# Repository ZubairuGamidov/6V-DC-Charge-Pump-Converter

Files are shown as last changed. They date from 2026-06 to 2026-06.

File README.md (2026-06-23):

# Low-Cost 6V DC-DC Charge Pump Converter

## 1. Introduction
The objective of this project is to design a low-cost charge pump circuit with a single input power source of 6V DC, satisfying all requirements like output load voltage, efficiency, voltage regulation, and cost-effectiveness. 

To meet these goals, the circuit utilizes an NE555 timer configured in astable mode to generate a switching signal. This signal is buffered by a BJT push-pull driver (using BC238 and BC308) to provide sufficient current to a multi-stage diode-capacitor voltage multiplier network. LTspice was used to build and test the circuit.

---

## 2. Design Specs & Laboratory Bench Results

The physical prototype was fabricated and tested in the laboratory using an oscilloscope, power supply, and multi-meter to verify compliance with design benchmarks:

* **Output Voltage (No Load):** Measured at **17.9V**, successfully staying under the maximum 20V constraint.
* **Output Voltage (Under $560\Omega$ Load):** Delivers a stable **16.2V**, comfortably exceeding the required 15.0V threshold.
* **Peak-to-Peak Output Ripple ($V_r$):** Measured at a very low **36.0mV** under full load, satisfying the noise restrictions.
* **System Power Efficiency ($\eta$):** Achieved **75.1%** overall efficiency during hardware testing.
* **Total Component Cost:** Calculated at **17.86 TL**, keeping the prototype well under the 20 TL budget cap.

---

## 3. Circuit Architecture
* **Astable Oscillator:** Configured via resistors $R_A = 1.2\text{k}\Omega$, $R_B = 12\text{k}\Omega$, and a $2.2\text{nF}$ ceramic capacitor to establish the system's operational switching frequency.
* **Buffer/Driver Stage:** A complementary BJT pair containing the **BC238 (NPN)** and **BC308 (PNP)** acting as a low-impedance high-current buffer to rapidly charge and discharge the multiplier network.
* **Multiplier Network:** A 2-stage voltage multiplication configuration utilizing four low forward-drop **1N5819 Schottky diodes** and $100\mu\text{F}$ electrolytic storage capacitors.

---

## 4. File Guide
* `Simulation/`: Contains the native LTspice transient simulation circuit file (`.asc`) and its corresponding analysis report.
* `Hardware/`: Contains the DipTrace schematic design (`.dch`) and hardware PCB layout (`.dip`) source files.
* `Production/`: Pre-packaged, standard-compliant Gerber and NC Drill manufacturing zip archive for automated fabrication.
* `Documentation/`: Full lab implementation report containing bench test photos, oscilloscope waveforms, and detailed efficiency metrics.

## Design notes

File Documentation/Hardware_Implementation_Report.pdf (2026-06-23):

### Low Cost DC-DC Converter

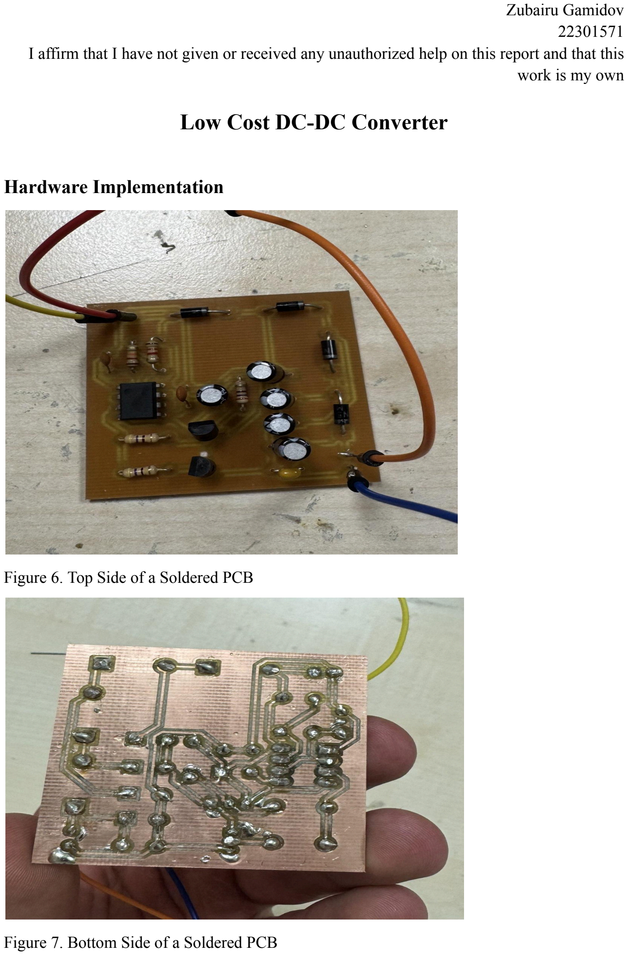
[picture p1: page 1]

Zubairu Gamidov
22301571
I affirm that I have not given or received any unauthorized help on this report and that this work is my own

Hardware Implementation

Figure 6. Top Side of a Soldered PCB

Figure 7. Bottom Side of a Soldered PCB

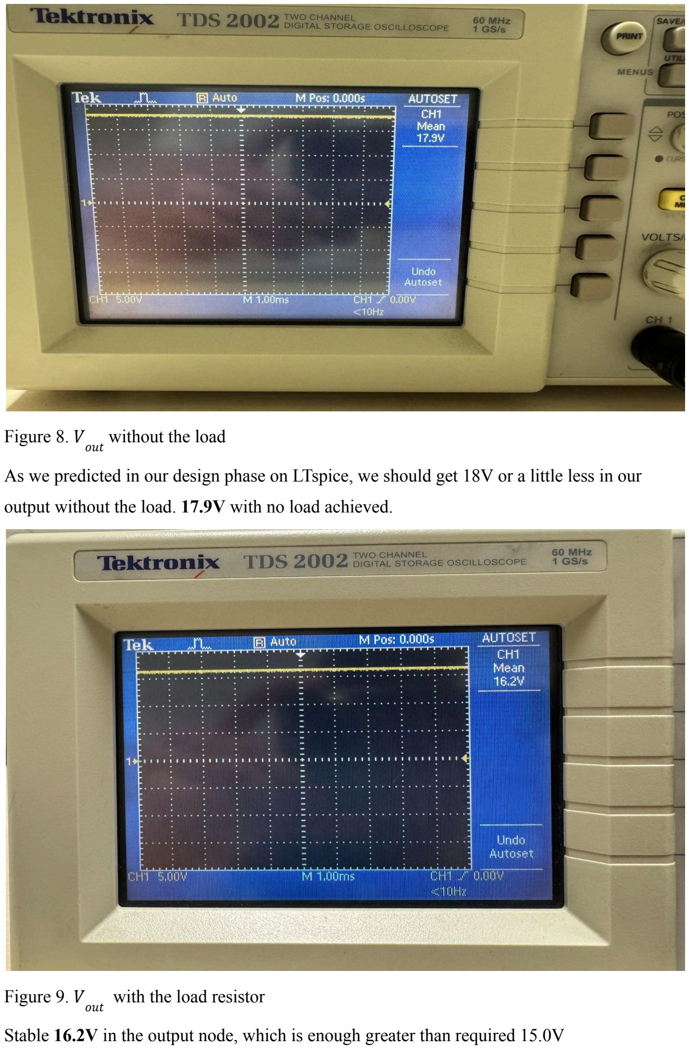
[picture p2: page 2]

Figure 8. V without the load
out
As we predicted in our design phase on LTspice, we should get 18V or a little less in our output without the load. 17.9V with no load achieved.

Figure 9. V with the load resistor
out
Stable 16.2V in the output node, which is enough greater than required 15.0V

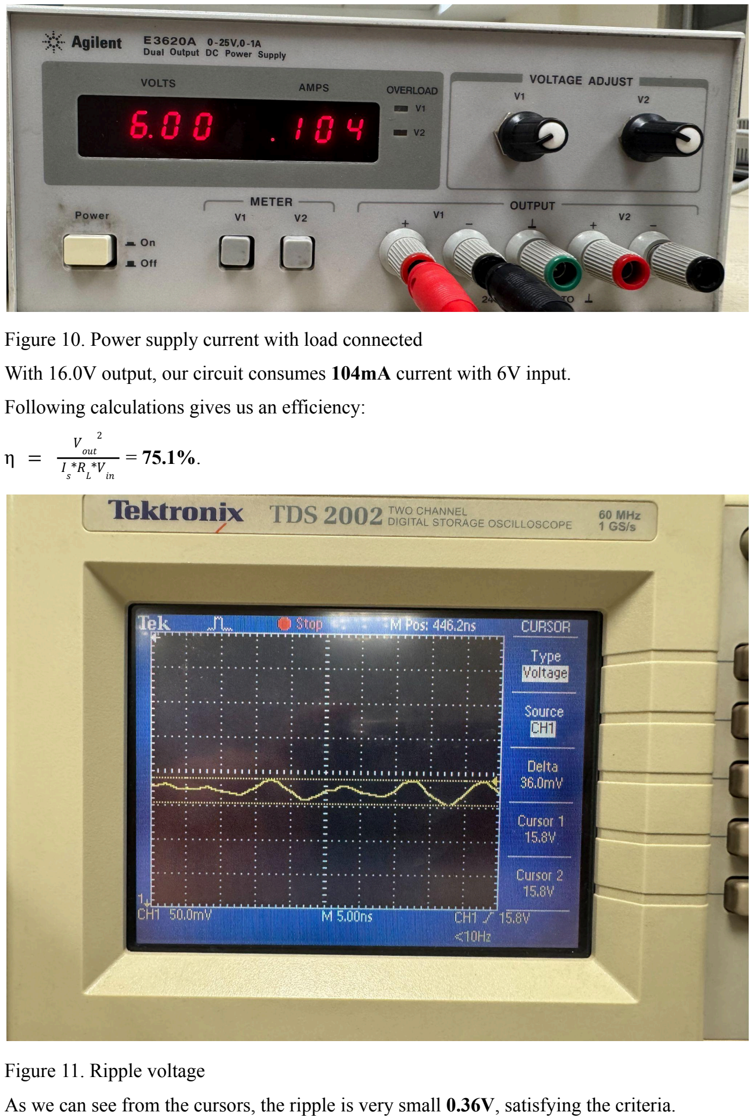
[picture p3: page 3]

Figure 10. Power supply current with load connected
With 16.0V output, our circuit consumes 104mA current with 6V input. Following calculations gives us an efficiency:
η = | = 75.1%.

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
Figure 11. Ripple voltage
As we can see from the cursors, the ripple is very small 0.36V, satisfying the criteria.

Components Cost

Component | Type | Quantity | Unit Price (TL) | Total (TL)
NE555 | Timer IC | 1 | 6.49 | 6.49
BC238 | NPN BJT | 1 | 1 | 1
BC308 | PNP BJT | 1 | 1.07 | 1.07
1N5819 | Schottky Diode | 4 | 1.06 | 4.24
100µF 25V | Electrolytic Capacitor | 5 | 0.7 | 3.5
2.2nF | Ceramic Capacitor | 2 | 0.29 | 0.58
0.47µF 63V | Ceramic Capacitor | 1 | 0.38 | 0.38
1/4W Resistors | Standard Resistors | 5 | 0.12 | 0.6
Grand Total | | | | 17.86 TL
Table 1. Cost Table

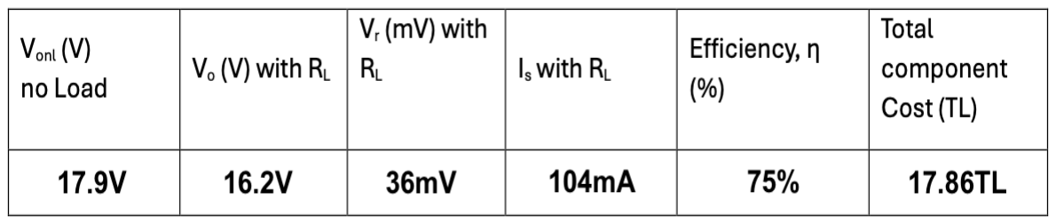
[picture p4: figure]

Figure 12. Final result table

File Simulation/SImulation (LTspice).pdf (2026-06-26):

Zubairu Gamidov
22301571

### Bilkent University

### EEE 313

### Charge Pump - Design Phase

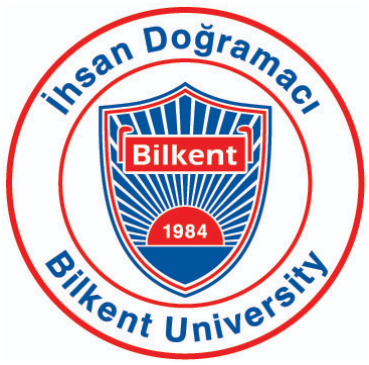
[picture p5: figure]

I affirm that I have not given or received any unauthorized help on this report and that this work is my own.

### 1. Introduction

The objective of this project is to design a low cost charge pump circuit with a single input power source of 6V DC, satisfying all requirements like output load voltage, efficiency, voltage regulation, and cost - effectiveness.

To meet these goals, the circuit utilizes an NE555 timer configured in astable mode to generate a switching signal. This signal is buffered by a BJT push-pull driver (using BC238 and BC308) to provide sufficient current to a multi-stage diode - capacitor voltage multiplier network. LTspice was used to build and test the circuit.

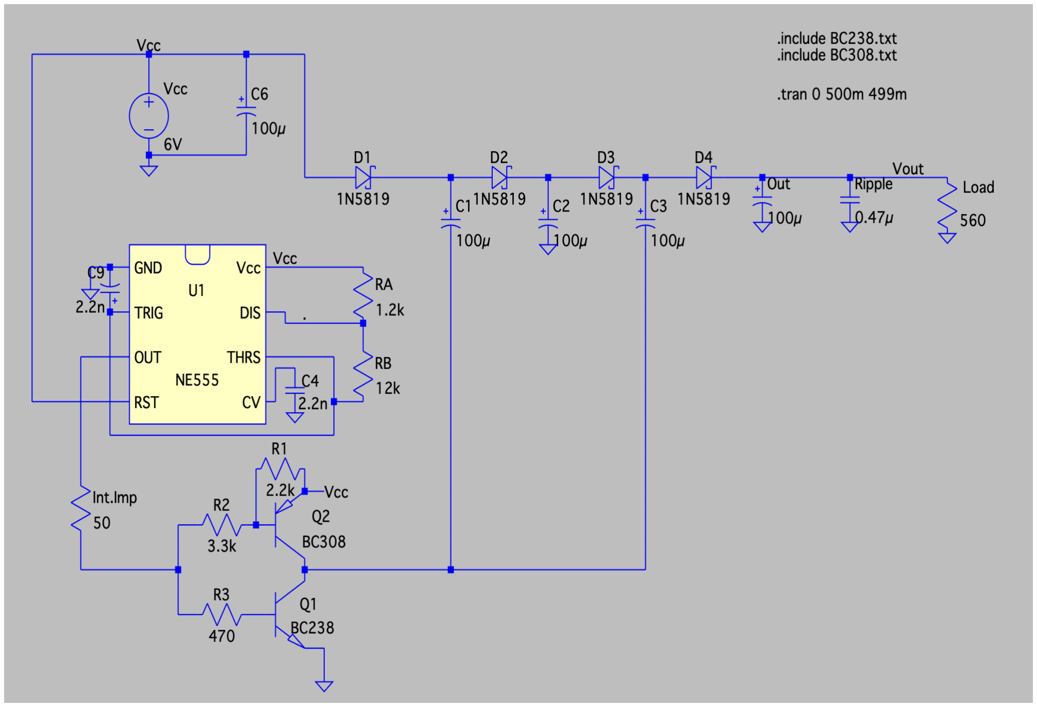
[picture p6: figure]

Figure 1. LTspice circuit design

### 2.1 NE555 Configuration

The timing characteristics are determined by resistors RA, RB, and the ceramic capacitor C9. To achieve high performance the following design choices were made:

### 1. Astable Mode: The NE555 is configured to oscillate continuously using a 6V power

supply.
2. 50% Duty Cycle: By choosing values for RA and RB (1k and 12k respectively), the
duty cycle is | 47.6%, which is acceptably close to the ideal value.. RB
RA+2RB | =
3. Frequency: The formula for frequency is F = | = 25.974kHz. ¹.44
(RA+RB)C9

### 2.2 Driver Configuration

BJT push-pull driver is implemented to act as an inverter and a high-current buffer. This stage is critical for ensuring that the charge pump capacitors C1 and C3 can be charged and discharged rapidly without overloading the our NE555 timer.

The driver utilizes a complementary pair of BJTs: an NPN BC238 (Q1) and a PNP BC308 (Q2). They are configured as a common-emitter inverter: When the NE555 output is high, Q1 is forward-biased and enters saturation, pulling the output node to GND. Conversely, when the NE555 output is low, our Q2 is forward-biased so it pulls the output node to the power supply Vcc voltage.

While the NE555 can typically provide up to 200mA, driving a heavy load like 560 Ohm and having two pumping stages can cause heating and voltage drop. This BJT stage provides a low - impedance path to the supply rails, with sharp switching transitions.

### 2.3 Charge Pump and Output Stage

To provide the necessary >15V to the output, we provided a two stage voltage multiplier network with 4 Schottky diodes (D1-D4) and three electrolyte capacitors 100uF each (C1-C3). We have two pumping capacitors, so the voltage stacks twice, first C1 is charged with Vcc + driver output (approximately 6V as well), after it translates to the C2 as a reservoir, after in C3 the voltage stacks again with driver out. Diodes are used to prevent the reverse current flowing. Moreover, diodes have internal voltage drop around 0.3V (Vd). Consequently, we have Vcc + 2x driver output (with some error) - 4Vd (diode voltage drop). After all of this voltage is stored in the final capacitor Cout with our load and the Cripple which is used to prevent high frequency switching noise.

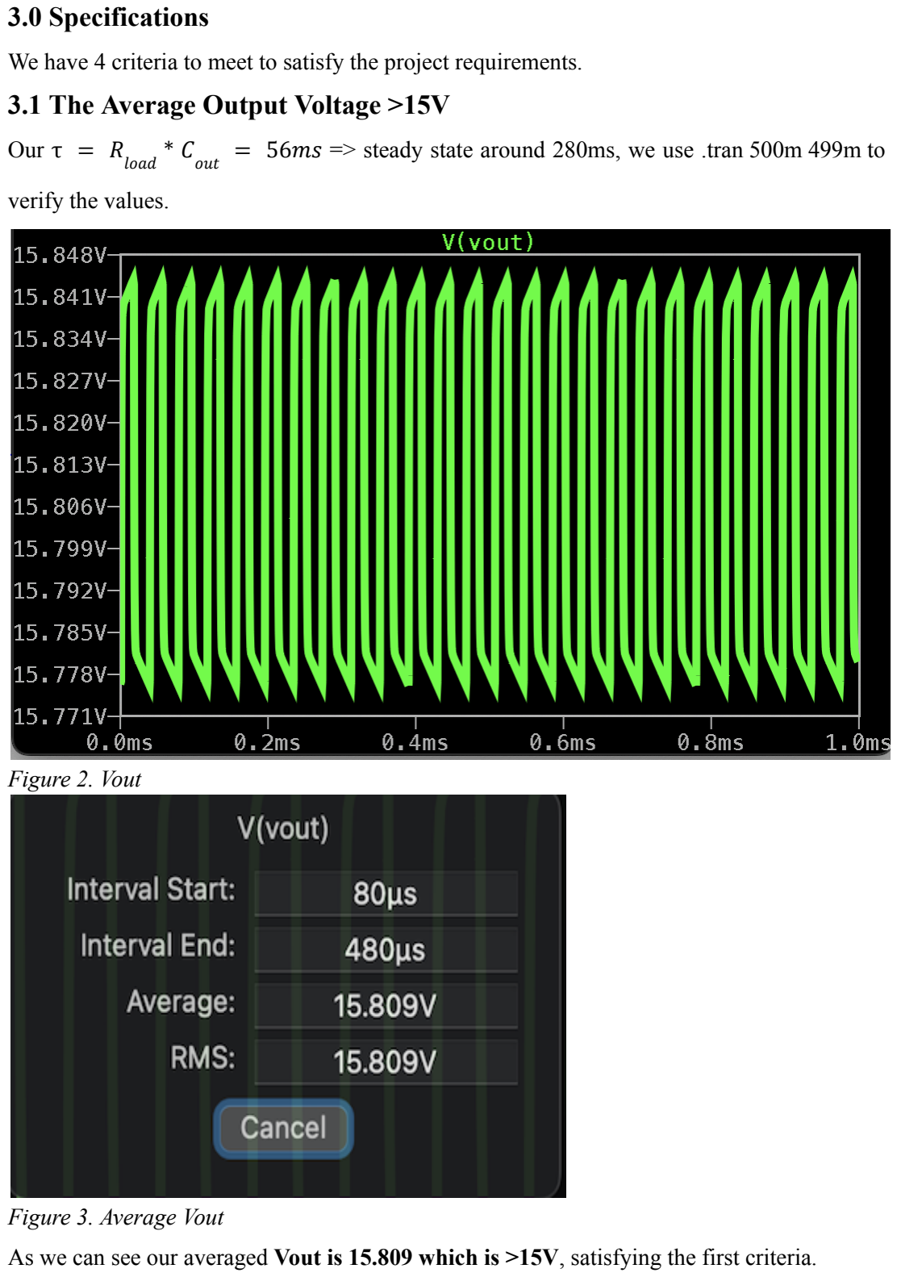
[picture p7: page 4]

### 3.0 Specifications

We have 4 criteria to meet to satisfy the project requirements.

### 3.1 The Average Output Voltage >15V

Our τ = R | => steady state around 280ms, we use .tran 500m 499m to load
* C

out = 56ms

verify the values.

Figure 2. Vout

Figure 3. Average Vout
As we can see our averaged Vout is 15.809 which is >15V, satisfying the first criteria.

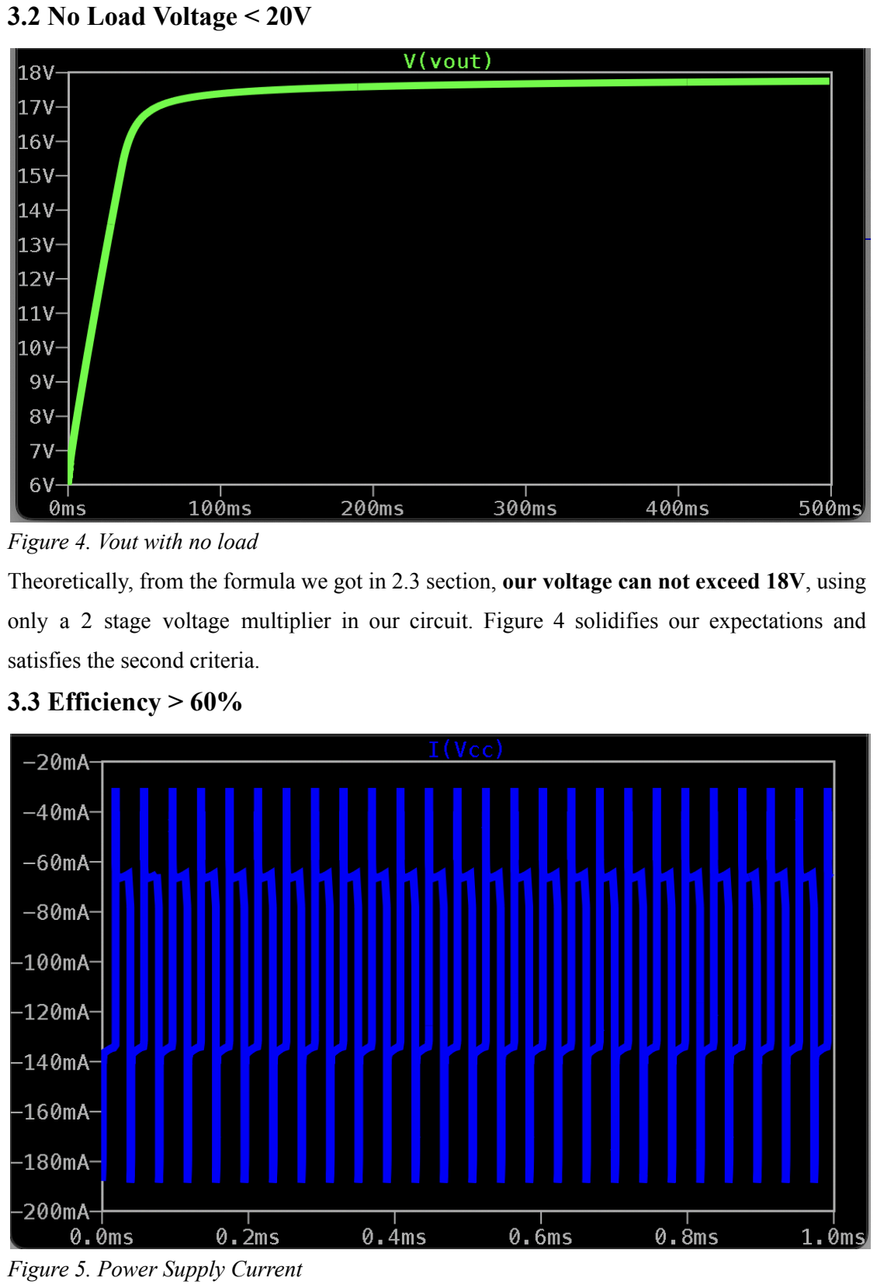
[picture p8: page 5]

### 3.2 No Load Voltage < 20V

Figure 4. Vout with no load
Theoretically, from the formula we got in 2.3 section, our voltage can not exceed 18V, using only a 2 stage voltage multiplier in our circuit. Figure 4 solidifies our expectations and satisfies the second criteria.

### 3.3 Efficiency > 60%

Figure 5. Power Supply Current

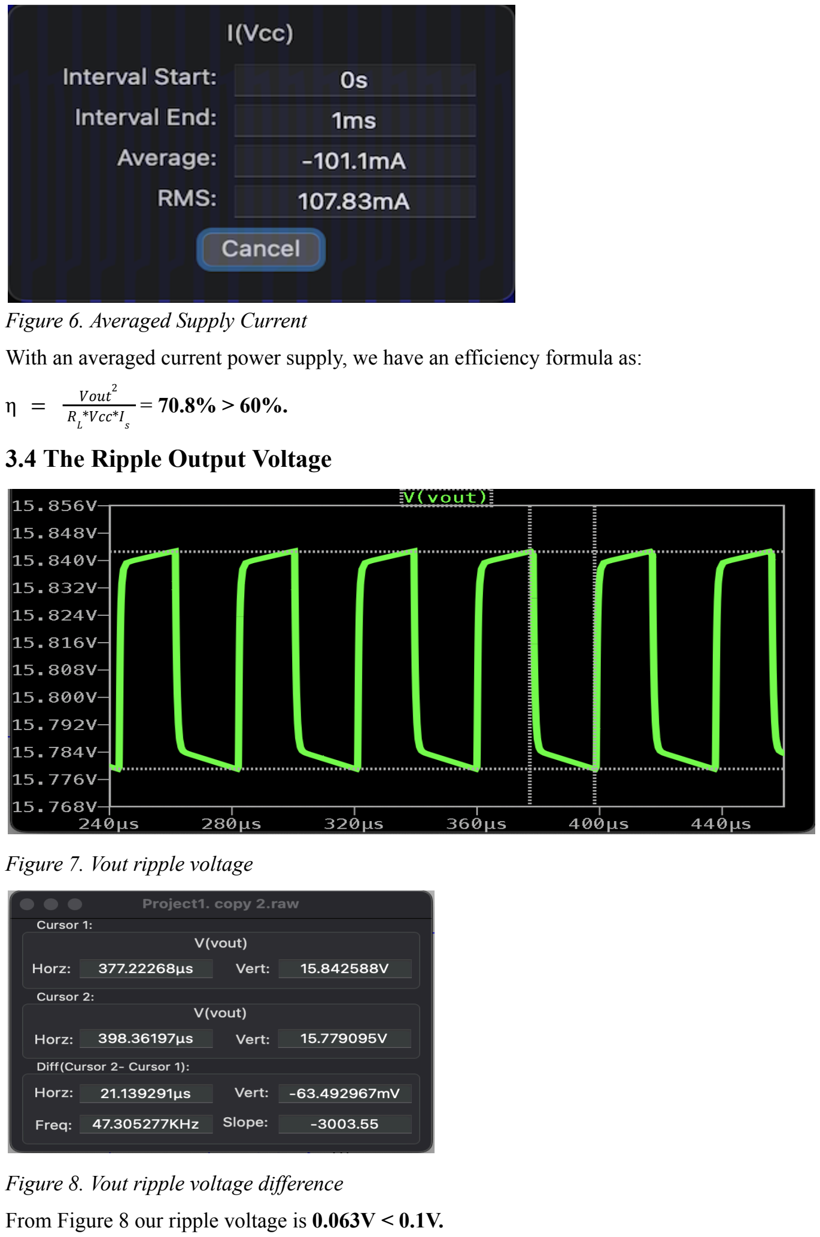
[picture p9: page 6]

Figure 6. Averaged Supply Current
With an averaged current power supply, we have an efficiency formula as:
η = | = 70.8% > 60%. Vout

2
R
L

*Vcc*I
s

### 3.4 The Ripple Output Voltage

Figure 7. Vout ripple voltage

Figure 8. Vout ripple voltage difference
From Figure 8 our ripple voltage is 0.063V < 0.1V.

### 3.5 Minimized Cost < 20TL

Component | Type | Quantity | Unit Price (TL) | Total (TL)
NE555 | Timer IC | 1 | 6.49 | 6.49
BC238 | NPN BJT | 1 | 1 | 1
BC308 | PNP BJT | 1 | 1.07 | 1.07
1N5819 | Schottky Diode | 4 | 1.06 | 4.24
100µF 25V | Electrolytic Capacitor | 5 | 0.7 | 3.5
2.2nF | Ceramic Capacitor | 2 | 0.29 | 0.29
0.47µF 63V | Ceramic Capacitor | 1 | 0.38 | 0.38
1/4W Resistors | Standard Resistors | 5 | 0.12 | 0.72
Grand Total | | | | 17.86 TL
Table 1. Cost Table
Our total cost is calculated to be 17.86TL < 20TL.

### 4.0 Conclusion

Our circuit successfully and comfortably achieved the required criteria, achieving more than 70% efficiency, and almost 16V output. At the same time, the rippling is moderate, and the voltage without load can not get above 18V in either case. Finally, 17.86TL total cost.

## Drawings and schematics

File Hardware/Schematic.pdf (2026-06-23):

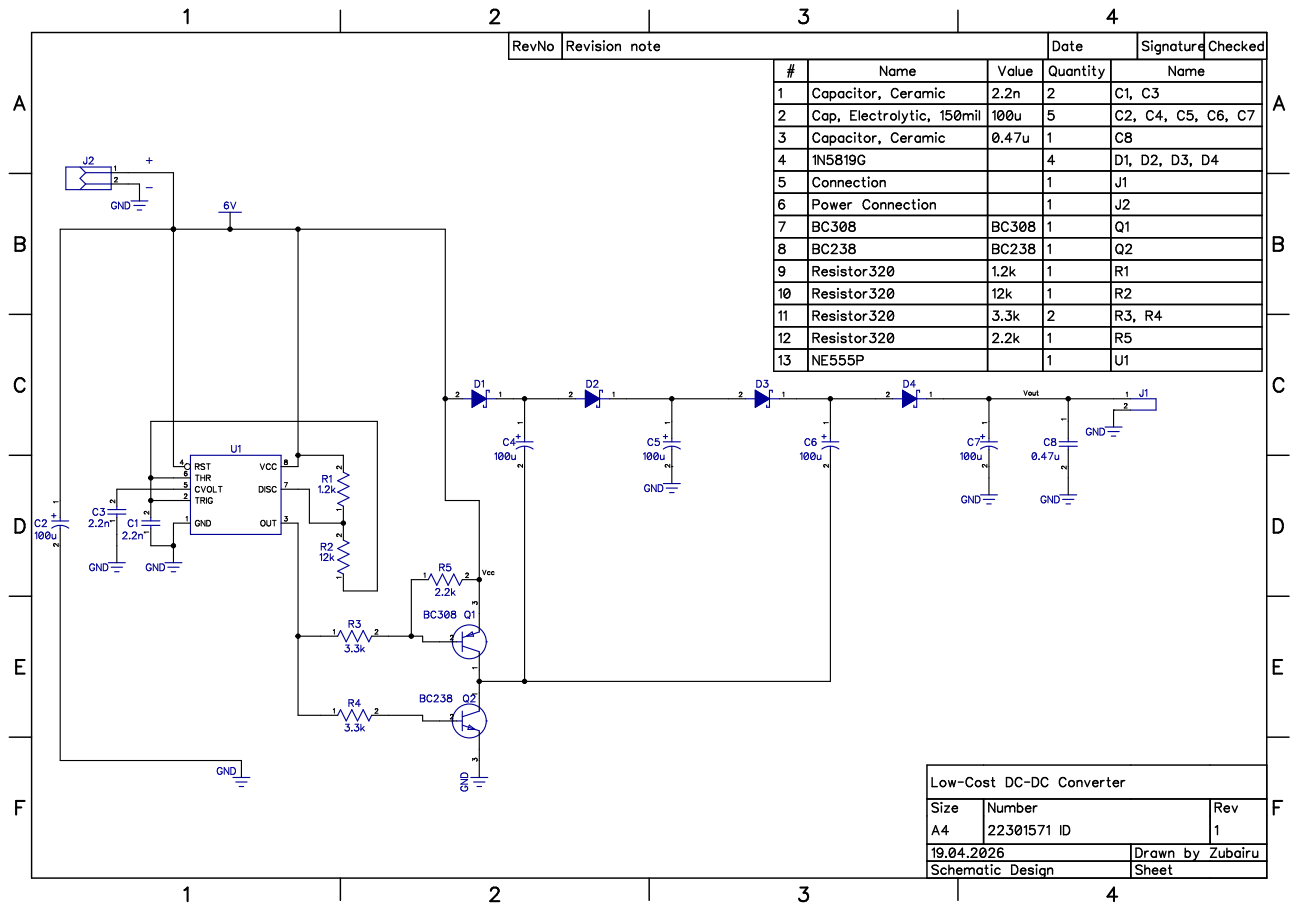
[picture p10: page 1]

Value

Capacitor, Ceramic | | | 2.2n
3 | Capacitor, Ceramic | | | 0.47u
4 | | 1N5819G
5 | Connection

Low-Cost DC-DC Converter
